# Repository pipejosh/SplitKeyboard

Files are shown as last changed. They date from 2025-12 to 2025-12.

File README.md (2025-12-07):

# Split keyboarddd

## WHY THO??

Weeeeell my wrists kinda hurt all of a sudde, so this is such a good opportunity to learn about keyboard developemt including creating a pcb, 3d modeling and budgeting a keyboard.

This project has been so much fun, although it was a pin at the beginnig, once I  got the hang off it, oufff boy, I was so much better

This keyboard is heavily inspired by a corne keyboard, specially the key layout

# IMAGESSS!!!

### render

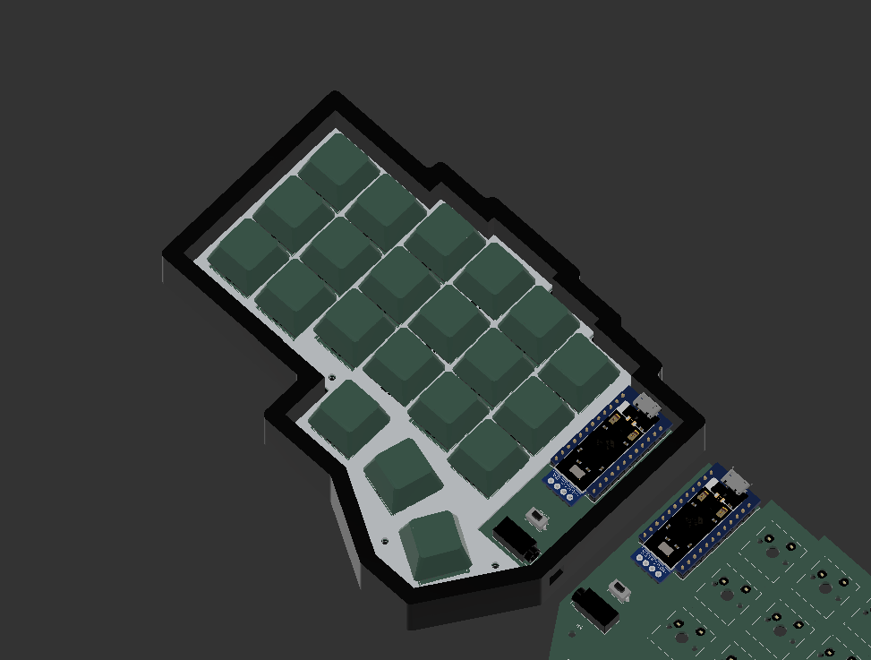
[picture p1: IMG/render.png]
render
 
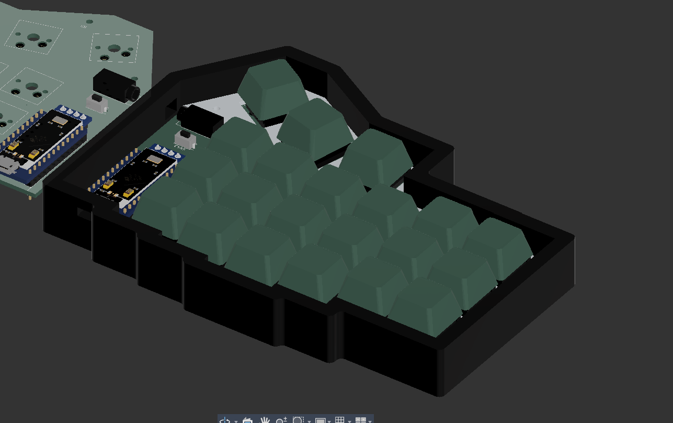
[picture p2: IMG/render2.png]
render2
 

###  case

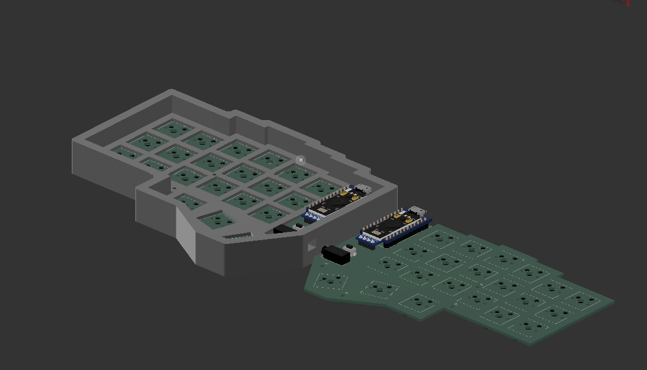
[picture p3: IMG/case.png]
case
 
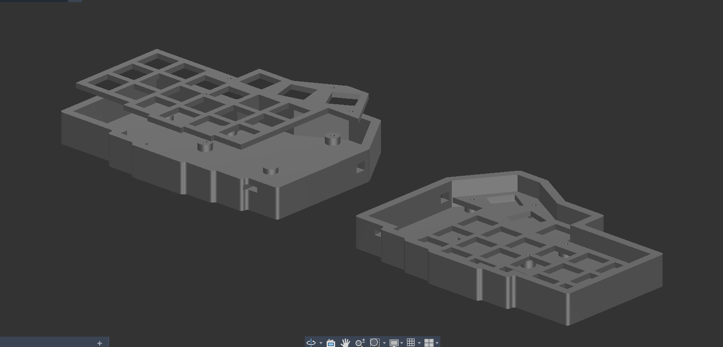
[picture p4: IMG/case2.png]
case
 

###  schematics

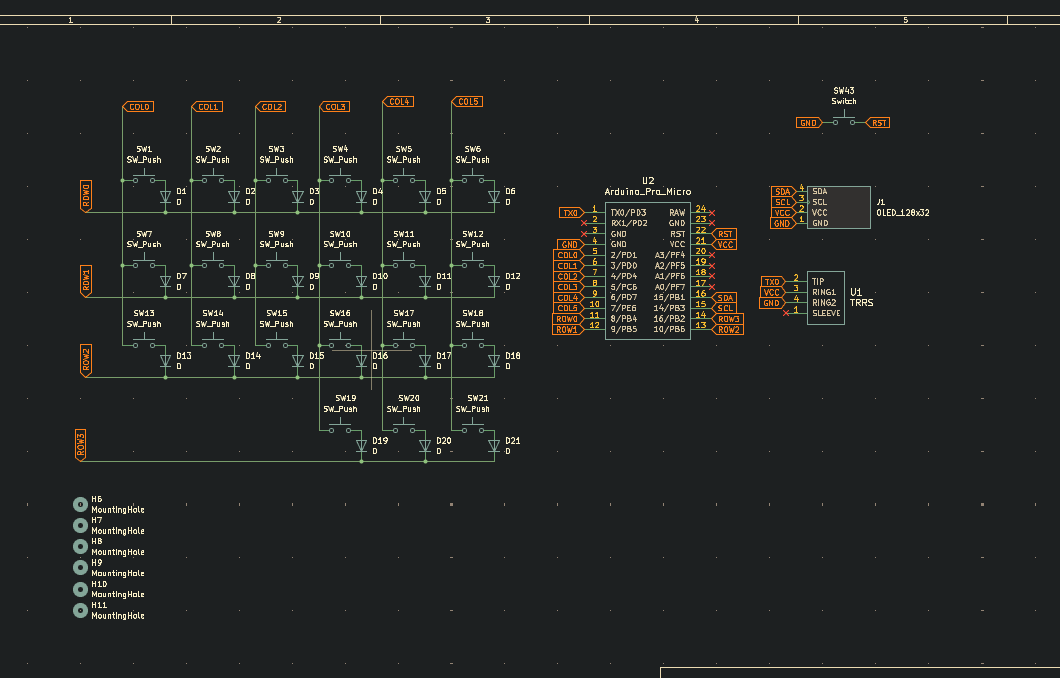
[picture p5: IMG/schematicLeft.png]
left side
 
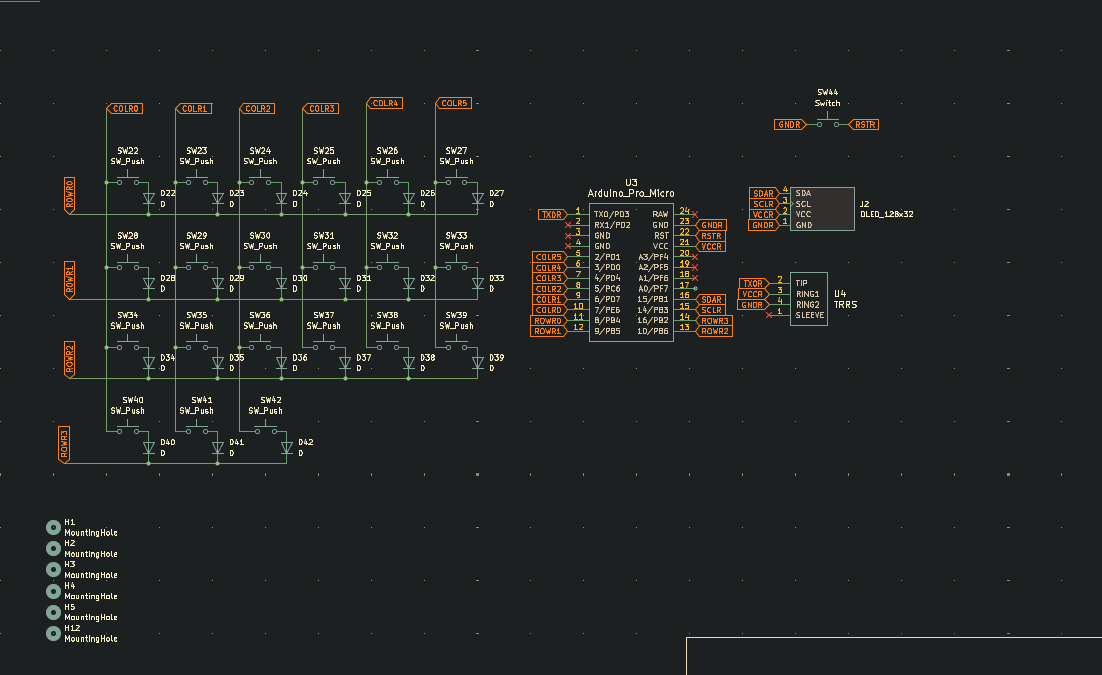
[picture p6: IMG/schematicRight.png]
 

###  pcb layout

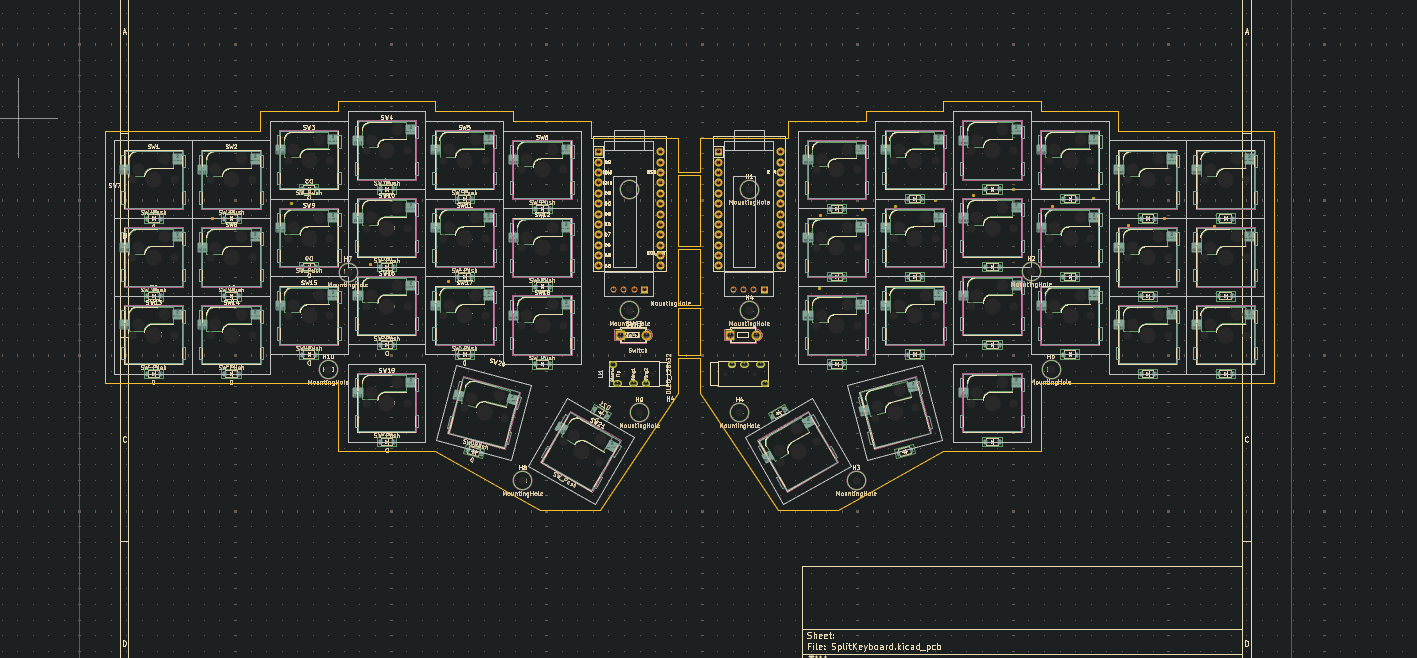
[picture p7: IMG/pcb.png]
pcb layout
 

###  BOM images
## Disclaimer (The currency for this purchases is Canadian Dollars)

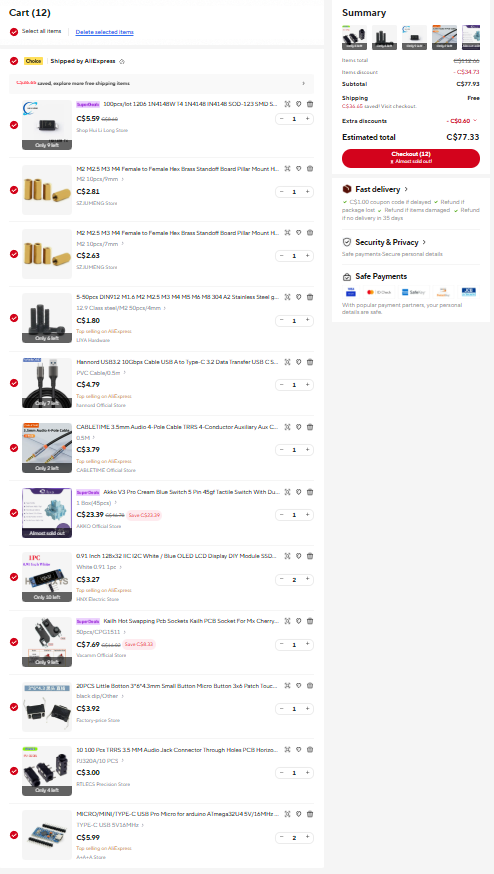
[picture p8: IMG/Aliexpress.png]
aliexpress
 
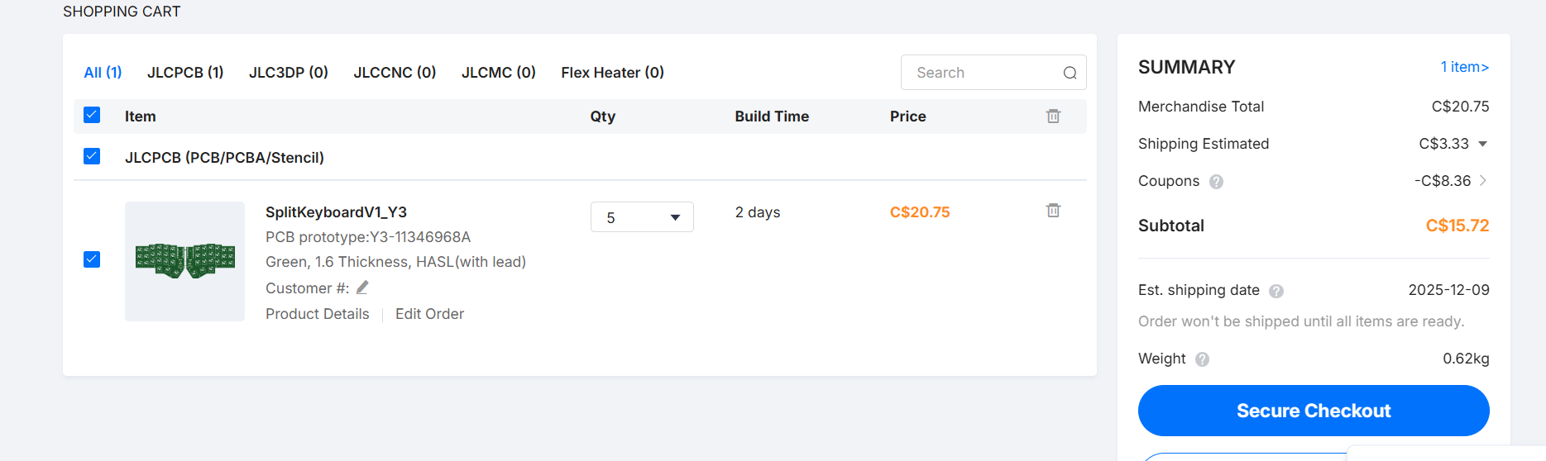
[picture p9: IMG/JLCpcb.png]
JLCpcb


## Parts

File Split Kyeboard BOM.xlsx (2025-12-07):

KIT Items | Description | Quantity | Unit Price (CAD) | Total Price (CAD) | URL
Arduino Pro Micro | Microcontroller | 1 | 6.09 | 12.18 | https://www.aliexpress.com/item/1576902211.html?srcSns=sns_Copy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
Smd diodes | Diodes | 100 | 0.04 | 4.34 | https://www.aliexpress.com/item/1005007160279747.html
trrs jack | Trrs conector | 10 | 0.30 | 3.04 | https://www.aliexpress.com/item/33029465106.html
Kailh hot swap | Hot swap for the switches | 50 | 0.16 | 7.79 | https://www.aliexpress.com/item/1005006610157756.html
Akko Creamy Blue | Switch | 45 | 0.53 | 23.79 | https://www.aliexpress.com/item/1005006382591392.html?spm=a2g0o.productlist.0.0.6c9fnDJunDJu8K&mp=1
Oled display | 0.91 inch oled display (white) | 2 | 3.31 | 6.62 | https://www.aliexpress.com/item/1005008918700196.html
M2 screw | M2 screws 5mm | 50 | 0.06 | 3.01 | https://www.aliexpress.com/item/1005005070119421.html
Trrs Cable | Trrs cable | 1 | 3.84 | 3.84 | https://www.amazon.ca/Coiled-Stereo-Haokiang-Extension-Headset/dp/B07FFW8YZR/ref=sr_1_13?sr=8-13
M2 standoff | M2 standoff 10mm | 15 | 0.18 | 2.76 | https://www.aliexpress.com/item/1005008798318304.html
Switches | Reset switch | 20 | 0.20 | 3.99 | https://www.aliexpress.com/item/1005009739698023.html
Usb c calbe | usdb cable | 1 | 9.08 | 9.08 | https://www.aliexpress.com/item/1005005315398342.html?spm=a2g0o.detail.0.0.6146jeKAjeKAgM&mp=1
Rubber feet | rubber feet for the keyboard |  | 0.06 | 2.95 | https://www.aliexpress.com/item/1005005315398342.html?spm=a2g0o.detail.0.0.6146jeKAjeKAgM&mp=1
taxes | aliexpress tax |  |  | 5
 |  |  | Components | 73.45
CASE Items | Description | Quantity | Unit Price ($) | Total Price ($) | URL
JLCPCB | Split keyboard PCB
JLCPCB Shipping | Shipping for PCB
Total | 89.17

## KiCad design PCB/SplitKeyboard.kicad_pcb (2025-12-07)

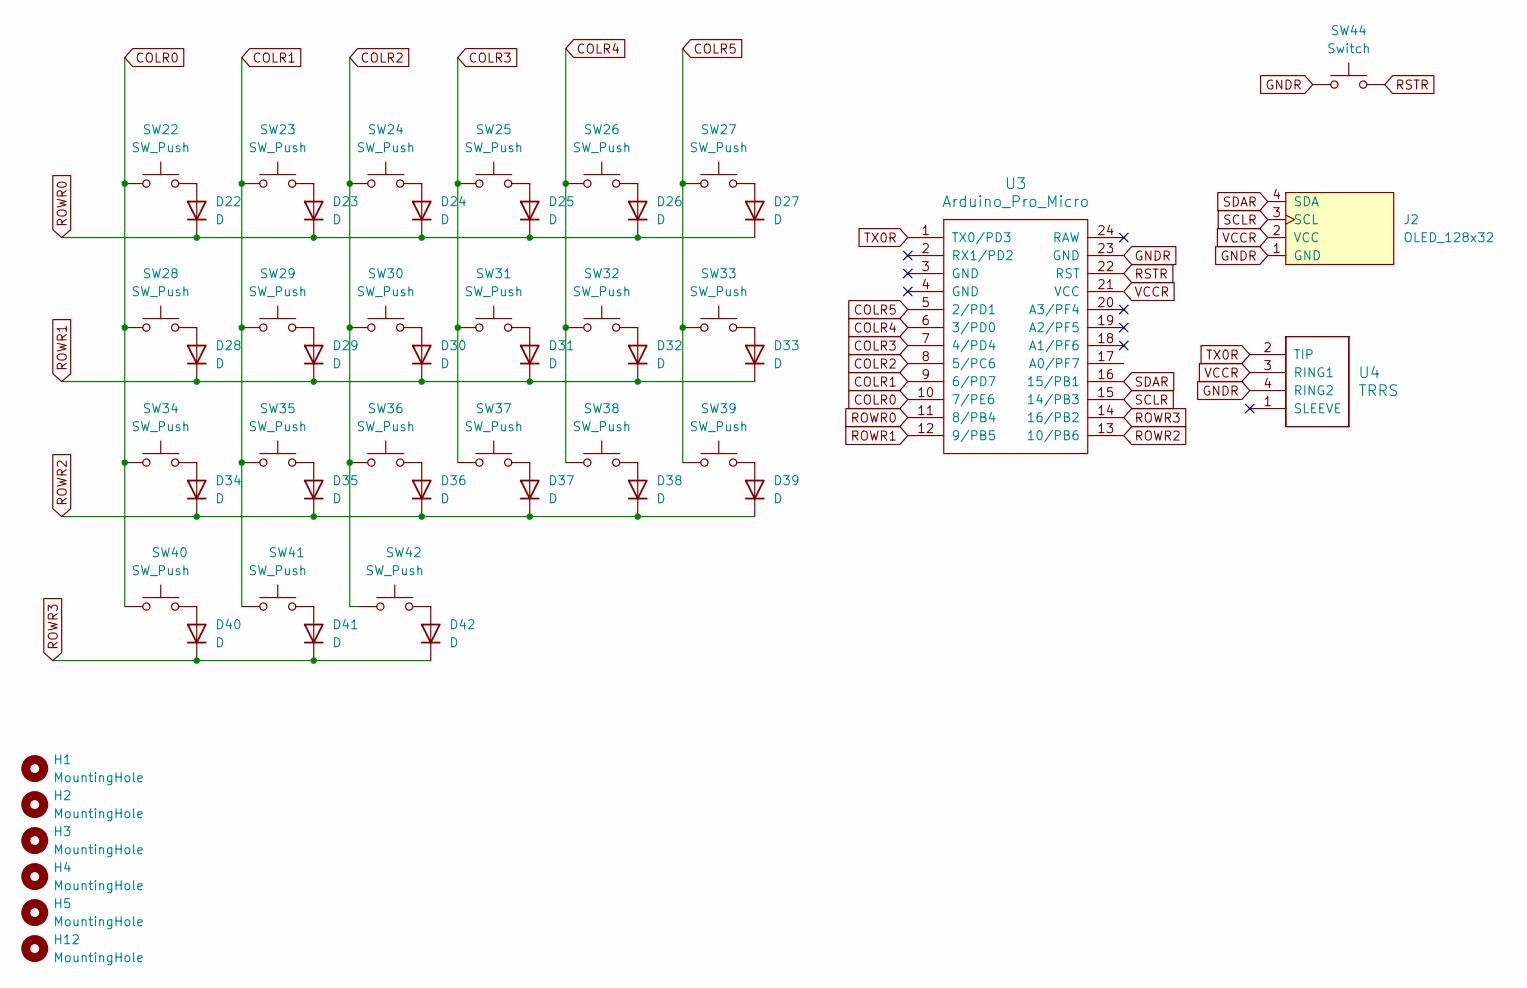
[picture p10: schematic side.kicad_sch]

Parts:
D22, D23, D24, D25, D26, D27, D28, D29, D30, D31, D32, D33, D34, D35, D36, D37, D38, D39, D40, D41, D42: D; Diode_SOD-123
H1, H2, H3, H4, H5, H12: MountingHole; MountingHole_2.2mm_M2
J2: OLED_128x32
SW22, SW23, SW24, SW25, SW26, SW27, SW28, SW29, SW30, SW31, SW32, SW33, SW34, SW35, SW36, SW37, SW38, SW39, SW40, SW41, SW42: SW_Push; Hotswap_MX_1.00u
SW44: Switch; Button_MJTP1243
U3: Arduino_Pro_Micro
U4: TRRS; TRRS_PJ-320A

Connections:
COLR0: SW22.1, SW28.1, SW34.1, SW40.1, U3.10 (7/PE6)
COLR1: SW23.1, SW29.1, SW35.1, SW41.1, U3.9 (6/PD7)
COLR2: SW24.1, SW30.1, SW36.1, SW42.1, U3.8 (5/PC6)
COLR3: SW25.1, SW31.1, SW37.1, U3.7 (4/PD4)
COLR4: SW26.1, SW32.1, SW38.1, U3.6 (3/PD0)
COLR5: SW27.1, SW33.1, SW39.1, U3.5 (2/PD1)
GNDR: J2.1 (GND), SW44.1, U3.23 (GND), U4.4 (RING2)
unnamed: D22.2 (A), SW22.2
unnamed: D23.2 (A), SW23.2
unnamed: D24.2 (A), SW24.2
unnamed: D25.2 (A), SW25.2
unnamed: D26.2 (A), SW26.2
unnamed: D27.2 (A), SW27.2
unnamed: D28.2 (A), SW28.2
unnamed: D29.2 (A), SW29.2
unnamed: D30.2 (A), SW30.2
unnamed: D31.2 (A), SW31.2
unnamed: D32.2 (A), SW32.2
unnamed: D33.2 (A), SW33.2
unnamed: D34.2 (A), SW34.2
unnamed: D35.2 (A), SW35.2
unnamed: D36.2 (A), SW36.2
unnamed: D37.2 (A), SW37.2
unnamed: D38.2 (A), SW38.2
unnamed: D39.2 (A), SW39.2
unnamed: D40.2 (A), SW40.2
unnamed: D41.2 (A), SW41.2
unnamed: D42.2 (A), SW42.2
ROWR0: D22.1 (K), D23.1 (K), D24.1 (K), D25.1 (K), D26.1 (K), D27.1 (K), U3.11 (8/PB4)
ROWR1: D28.1 (K), D29.1 (K), D30.1 (K), D31.1 (K), D32.1 (K), D33.1 (K), U3.12 (9/PB5)
ROWR2: D34.1 (K), D35.1 (K), D36.1 (K), D37.1 (K), D38.1 (K), D39.1 (K), U3.13 (10/PB6)
ROWR3: D40.1 (K), D41.1 (K), D42.1 (K), U3.14 (16/PB2)
RSTR: SW44.2, U3.22 (RST)
SCLR: J2.3 (SCL), U3.15 (14/PB3)
SDAR: J2.4 (SDA), U3.16 (15/PB1)
TX0R: U3.1 (TX0/PD3), U4.2 (TIP)
VCCR: J2.2 (VCC), U3.21 (VCC), U4.3 (RING1)

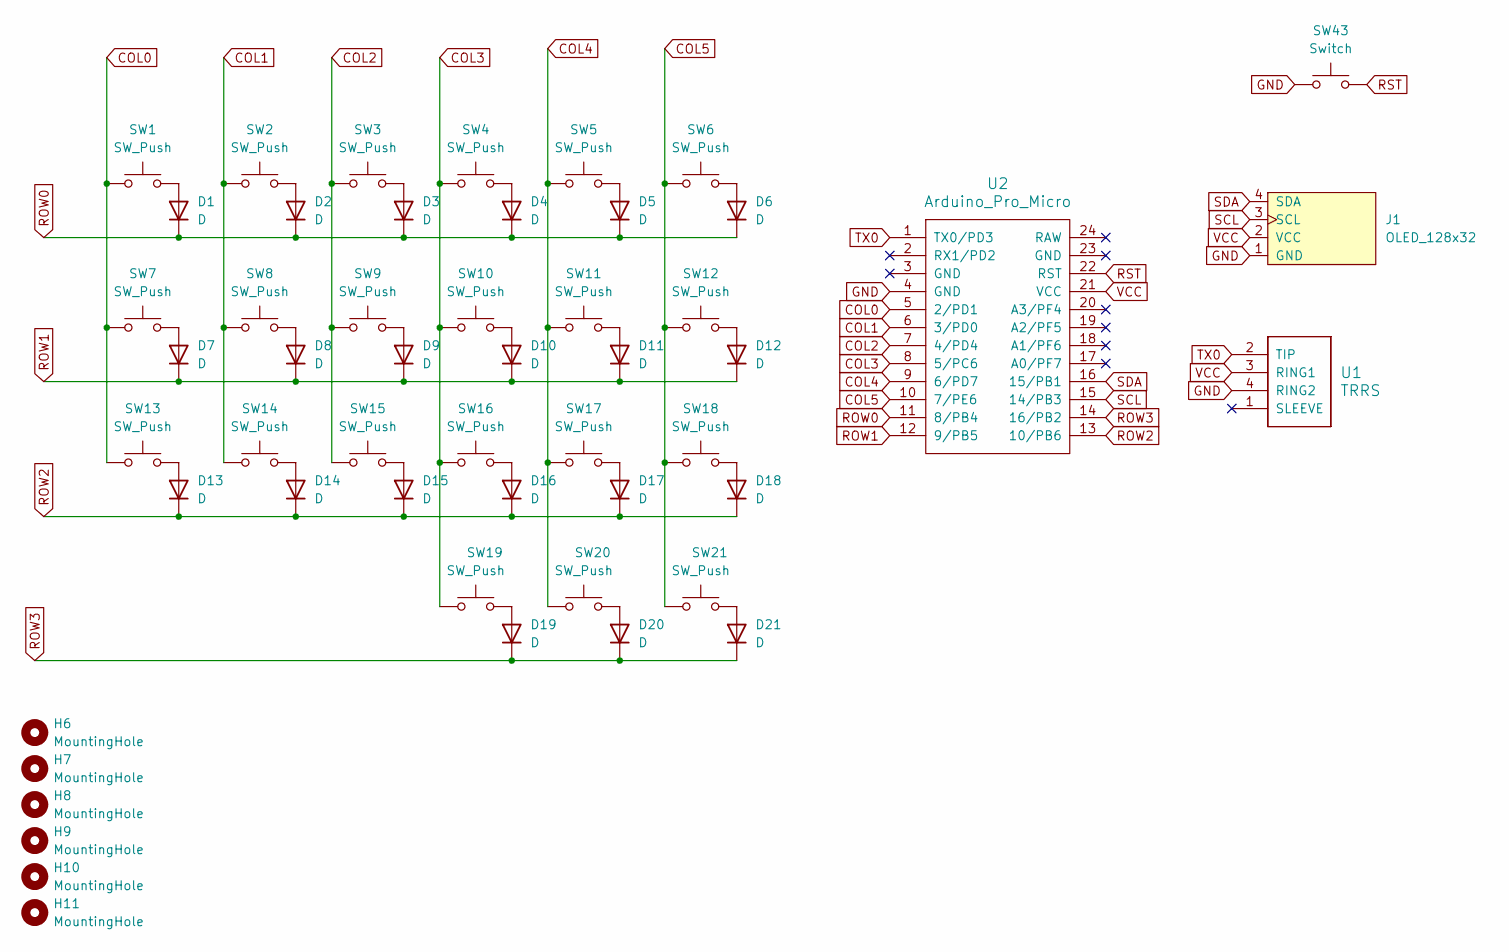
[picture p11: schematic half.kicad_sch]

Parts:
D1, D2, D3, D4, D5, D6, D7, D8, D9, D10, D11, D12, D13, D14, D15, D16, D17, D18, D19, D20, D21: D; Diode_SOD-123
H6, H7, H8, H9, H10, H11: MountingHole; MountingHole_2.2mm_M2
J1: OLED_128x32
SW1, SW2, SW3, SW4, SW5, SW6, SW7, SW8, SW9, SW10, SW11, SW12, SW13, SW14, SW15, SW16, SW17, SW18, SW19, SW20, SW21: SW_Push; Hotswap_MX_1.00u
SW43: Switch; Button_MJTP1243
U1: TRRS; TRRS_PJ-320A
U2: Arduino_Pro_Micro

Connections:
COL0: SW1.1, SW7.1, SW13.1, U2.5 (2/PD1)
COL1: SW2.1, SW8.1, SW14.1, U2.6 (3/PD0)
COL2: SW3.1, SW9.1, SW15.1, U2.7 (4/PD4)
COL3: SW4.1, SW10.1, SW16.1, SW19.1, U2.8 (5/PC6)
COL4: SW5.1, SW11.1, SW17.1, SW20.1, U2.9 (6/PD7)
COL5: SW6.1, SW12.1, SW18.1, SW21.1, U2.10 (7/PE6)
GND: J1.1 (GND), SW43.1, U1.4 (RING2), U2.4 (GND)
unnamed: D1.2 (A), SW1.2
unnamed: D2.2 (A), SW2.2
unnamed: D3.2 (A), SW3.2
unnamed: D4.2 (A), SW4.2
unnamed: D5.2 (A), SW5.2
unnamed: D6.2 (A), SW6.2
unnamed: D7.2 (A), SW7.2
unnamed: D8.2 (A), SW8.2
unnamed: D9.2 (A), SW9.2
unnamed: D10.2 (A), SW10.2
unnamed: D11.2 (A), SW11.2
unnamed: D12.2 (A), SW12.2
unnamed: D13.2 (A), SW13.2
unnamed: D14.2 (A), SW14.2
unnamed: D15.2 (A), SW15.2
unnamed: D16.2 (A), SW16.2
unnamed: D17.2 (A), SW17.2
unnamed: D18.2 (A), SW18.2
unnamed: D19.2 (A), SW19.2
unnamed: D20.2 (A), SW20.2
unnamed: D21.2 (A), SW21.2
ROW0: D1.1 (K), D2.1 (K), D3.1 (K), D4.1 (K), D5.1 (K), D6.1 (K), U2.11 (8/PB4)
ROW1: D7.1 (K), D8.1 (K), D9.1 (K), D10.1 (K), D11.1 (K), D12.1 (K), U2.12 (9/PB5)
ROW2: D13.1 (K), D14.1 (K), D15.1 (K), D16.1 (K), D17.1 (K), D18.1 (K), U2.13 (10/PB6)
ROW3: D19.1 (K), D20.1 (K), D21.1 (K), U2.14 (16/PB2)
RST: SW43.2, U2.22 (RST)
SCL: J1.3 (SCL), U2.15 (14/PB3)
SDA: J1.4 (SDA), U2.16 (15/PB1)
TX0: U1.2 (TIP), U2.1 (TX0/PD3)
VCC: J1.2 (VCC), U1.3 (RING1), U2.21 (VCC)

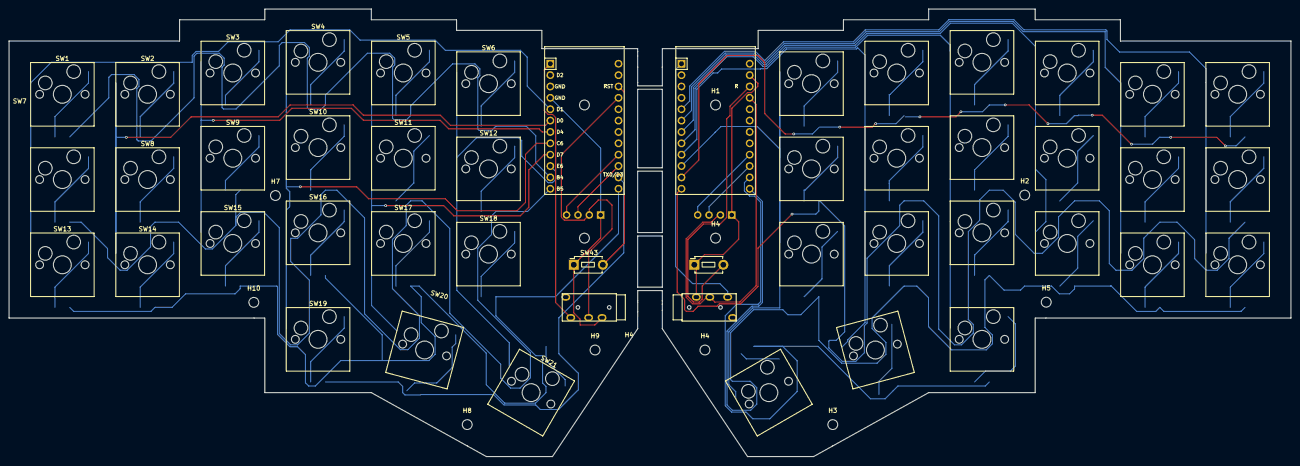
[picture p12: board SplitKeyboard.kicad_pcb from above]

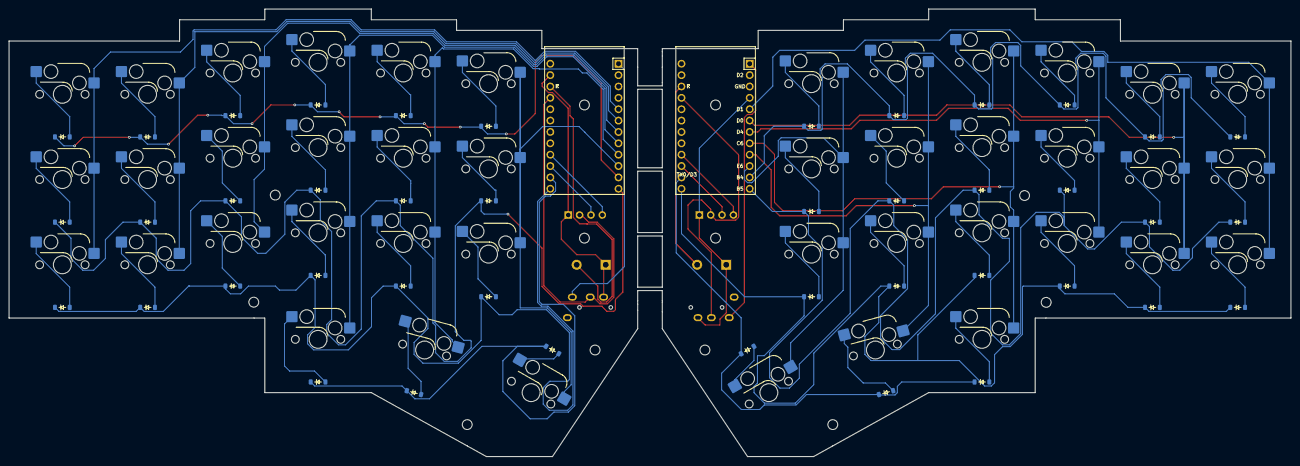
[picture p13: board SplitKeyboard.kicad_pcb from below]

Board: 2 copper layers, 286.5 x 100.0 mm, 104 parts (42 on the bottom side), 74 nets.

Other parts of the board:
H4#2, H4#3: MountingHole; MountingHole_2.2mm_M2

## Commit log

2025-12-07 update render
    [SplitKeyboard.kicad_pcb]
2025-12-07 edit BOM
    [Split Kyeboard BOM.xlsx]
2025-12-07 update BOM image
    [Split Kyeboard BOM.xlsx]
2025-12-16 updatae BOM
